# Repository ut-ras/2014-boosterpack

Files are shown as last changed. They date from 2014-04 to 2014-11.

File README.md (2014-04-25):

2014-boosterpack
================
This repo contains the eagle source for a boosterpack designed for the Stellaris/Tiva lm4f/tm4c launchpads.

TODO
================
* buck regulator circuit for bat -> vbus of launchpad
* buck regulator circuit for bat -> 5V servos
* headers for the launchpad
* motor driver circuit for driving two motors from battery power
* headers of power, ground, signal trios

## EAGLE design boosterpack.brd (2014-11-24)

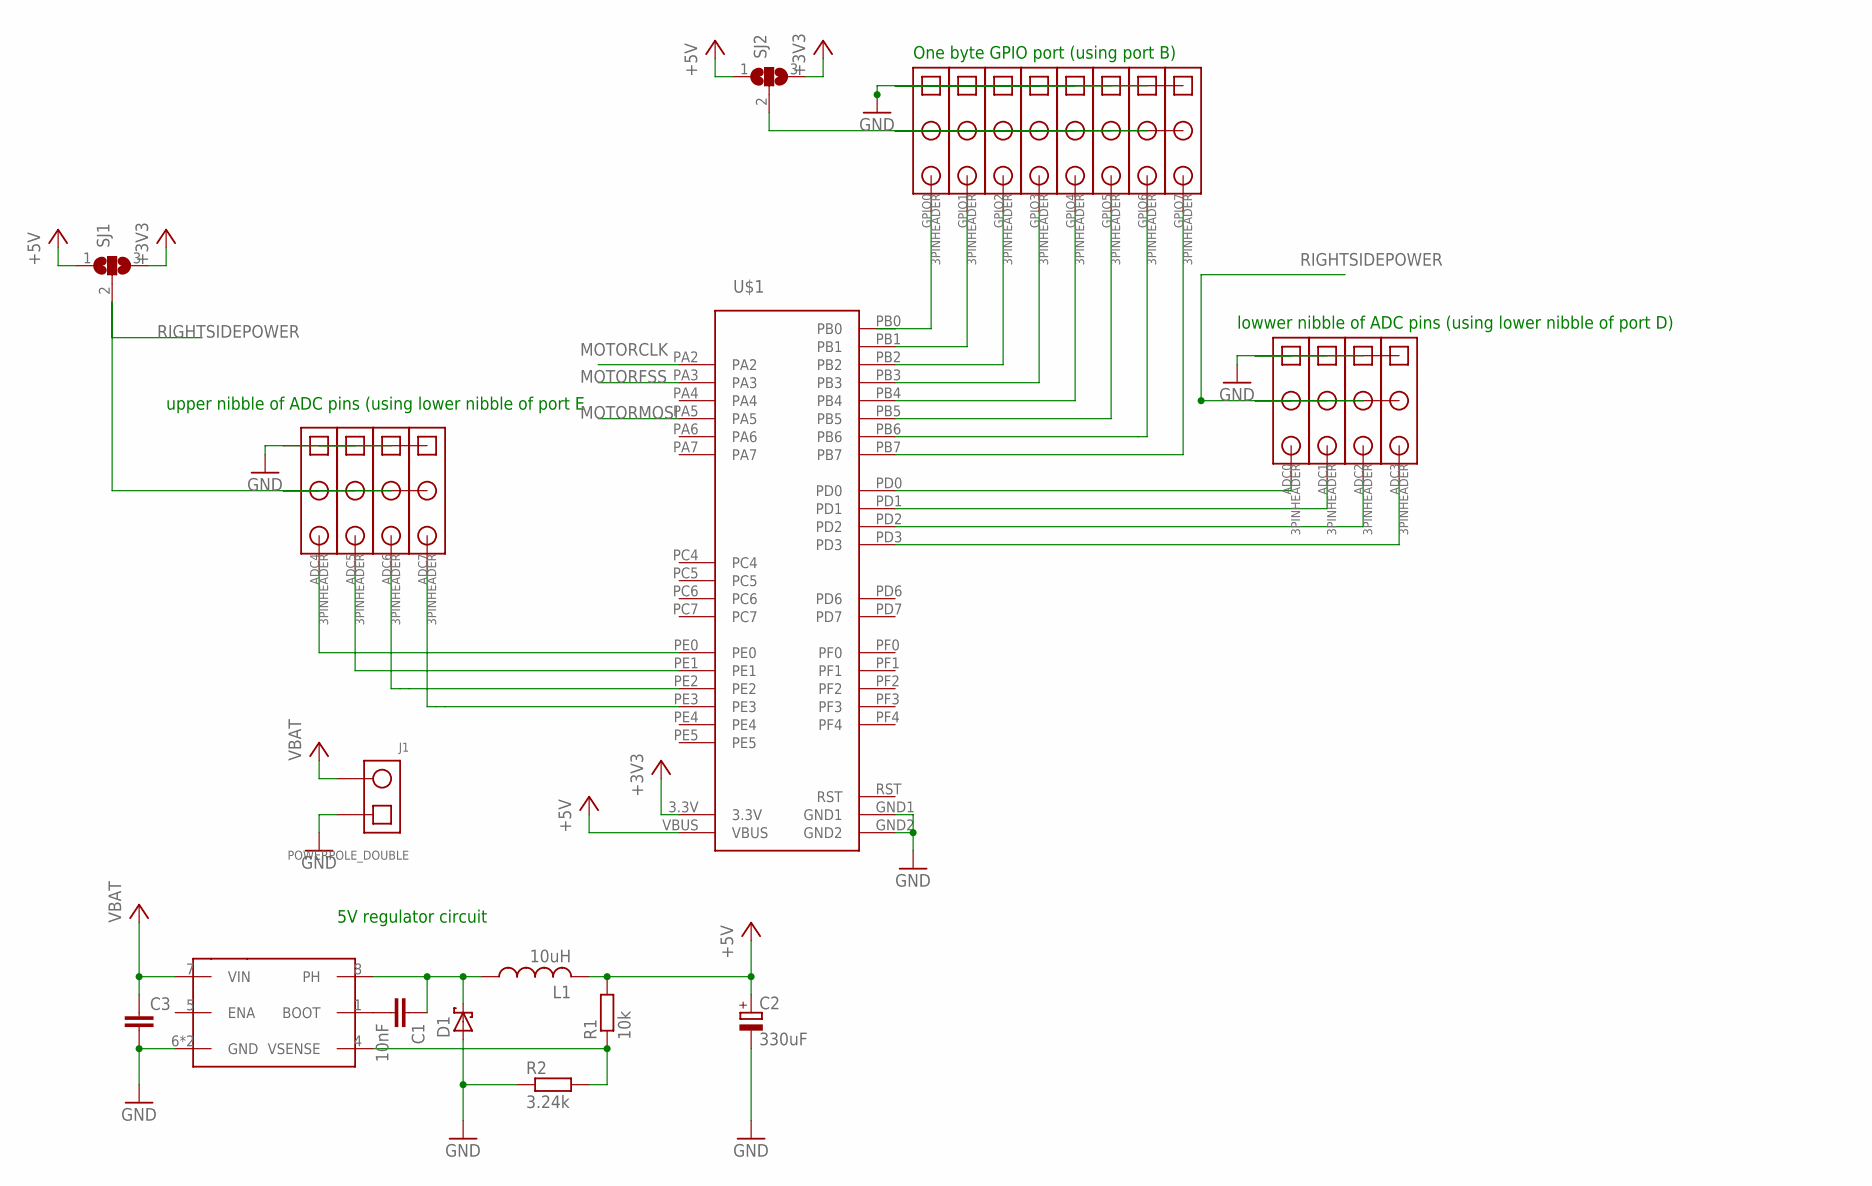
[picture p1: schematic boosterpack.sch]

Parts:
ADC0, ADC1, ADC2, ADC3, ADC4, ADC5, ADC6, ADC7: 3PINHEADER
C1: 10nF; C025-024X044
C2: 330uF; B45181A
C3: C-EU025-024X044; C025-024X044
D1: SCHOTTKY-DIODEDO35-7; DO35-7
GPIO0, GPIO1, GPIO2, GPIO3, GPIO4, GPIO5, GPIO6, GPIO7: 3PINHEADER
J1: POWERPOLE_DOUBLE
L1: 10uH; SDR1006
R1: 10k; 0204/5
R2: 3.24k; 0204/5
SJ1, SJ2: SJ2W; SJ_2
U$1: STELLARIS-LAUNCHPADSTELLARIS-LAUNCHPAD-XL; LAUNCHPAD-XL
U$2: TPS5450; DDS

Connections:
+3V3: SJ1.3, SJ2.3, U$1.3.3V
+5V: C2.+, L1.P$2 (2), R1.2, SJ1.1, SJ2.1, U$1.VBUS
ADC1: ADC1.3, U$1.PD1
ADC2: ADC2.3, U$1.PD2
ADC3: ADC3.3, U$1.PD3
ADC5: ADC5.3, U$1.PE1
GND: ADC0.1, ADC1.1, ADC2.1, ADC3.1, ADC4.1, ADC5.1, ADC6.1, ADC7.1, C2.-, C3.2, D1.A, GPIO0.1, GPIO1.1, GPIO2.1, GPIO3.1, GPIO4.1, GPIO5.1, GPIO6.1, GPIO7.1, J1.1, R2.1, U$1.GND1, U$1.GND2, U$2.6 (GND), U$2.GROUNDPAD (GND)
GPIO0: GPIO0.3, U$1.PB0
GPIO1: GPIO1.3, U$1.PB1
GPIO2: GPIO2.3, U$1.PB2
GPIO3: GPIO3.3, U$1.PB3
MOTORCLK: U$1.PA2
MOTORFSS: U$1.PA3
MOTORMOSI: U$1.PA5
unnamed: ADC0.3, U$1.PD0
unnamed: GPIO4.3, U$1.PB4
unnamed: GPIO5.3, U$1.PB5
unnamed: ADC6.3, U$1.PE2
unnamed: ADC7.3, U$1.PE3
unnamed: GPIO6.3, U$1.PB6
unnamed: GPIO0.2, GPIO1.2, GPIO2.2, GPIO3.2, GPIO4.2, GPIO5.2, GPIO6.2, GPIO7.2, SJ2.2
unnamed: GPIO7.3, U$1.PB7
unnamed: C1.2, U$2.1 (BOOT)
unnamed: R1.1, R2.2, U$2.4 (VSENSE)
unnamed: C1.1, D1.C, L1.P$1 (1), U$2.8 (PH)
unnamed: ADC4.3, U$1.PE0
RIGHTSIDEPOWER: ADC0.2, ADC1.2, ADC2.2, ADC3.2, ADC4.2, ADC5.2, ADC6.2, ADC7.2, SJ1.2
RST: U$1.RST
VCC: C3.1, J1.2, U$2.7 (VIN)

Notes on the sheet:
One byte GPIO port (using port B)
lowwer nibble of ADC pins (using lower nibble of port D)
upper nibble of ADC pins (using lower nibble of port E
5V regulator circuit

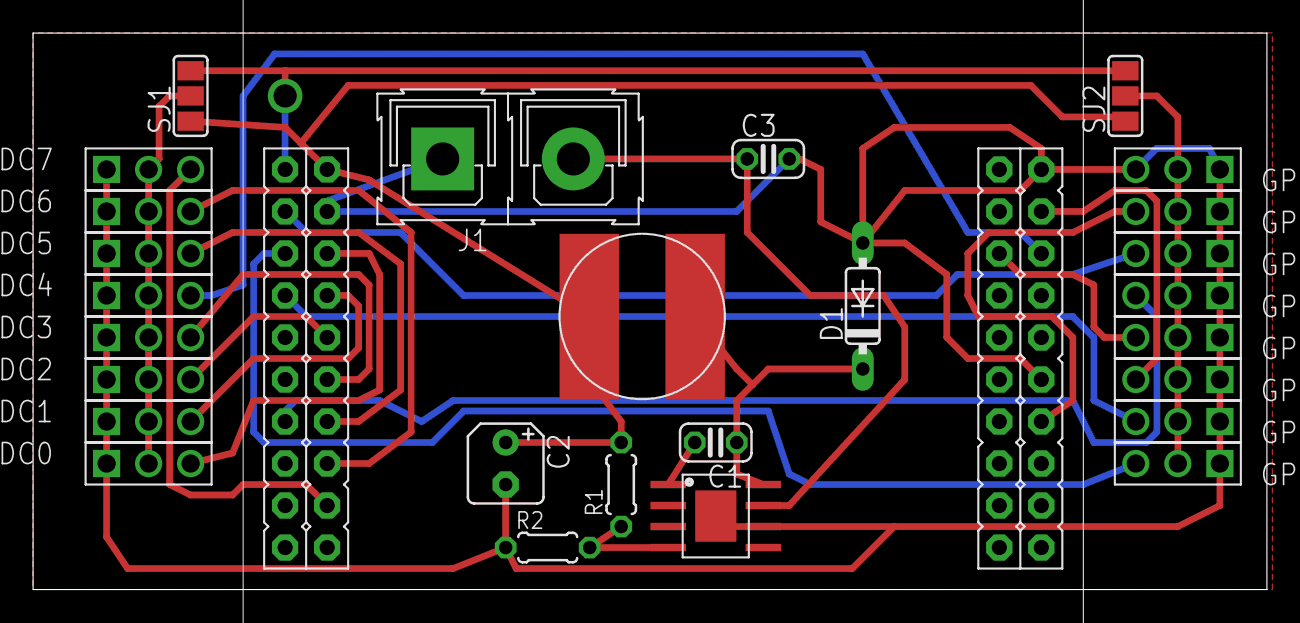
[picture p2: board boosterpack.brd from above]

Board: 2 copper layers, 74.6 x 33.6 mm, 28 parts (0 on the bottom side), 25 nets.

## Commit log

2014-04-25 added inital schematic which specifies the pin assignments for the two bytes of direct IO
    [boosterpack.sch]
2014-04-25 inital layout of the header on the 'board'
    [boosterpack.brd]
2014-04-25 added power regulating circiut
    [boosterpack.brd, boosterpack.sch]
2014-04-25 new layout for the reg circuit
    I feel like explaining my use of the smd inductor
    * it's small ~10mm wide by ~6mm tall
    * it's easy to solder (it's a huge smd part afterall)
    * it's cheip $0.60
    * it makes putting the regulator under the launchpad possible
    * it brings down the surface area by about half compared to other parts
    [boosterpack.brd, boosterpack.sch]
2014-04-25 lots of routing; moustly just routing
    [boosterpack.brd, boosterpack.sch]
2014-04-26 flipped the adc's and the gpio's; fewer wires are going across the middle
    [boosterpack.brd]
2014-04-26 added diode i forgot; routed new diode
    [boosterpack.brd, boosterpack.sch]
2014-04-28 added spi motor driver for two motors
    [boosterpack.brd, boosterpack.sch]
2014-04-29 fixed 3v3 not connecting to the motor drivers and rerouted some stuff
    [boosterpack.brd, boosterpack.sch]
2014-04-29 added mounting holes; moved motors to a better spot
    [boosterpack.brd]
2014-11-24 Removed motor drivers, almost done wiring board
    [boosterpack.brd, boosterpack.sch]
